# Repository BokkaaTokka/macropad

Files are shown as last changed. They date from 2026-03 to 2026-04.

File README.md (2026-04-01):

# CadPad
**This is my own macropad called CadPad.**

CadPad is designed to provide shortcuts in CAD, but also works for other things by mapping it to anything you want. It is also my very first PCB design.

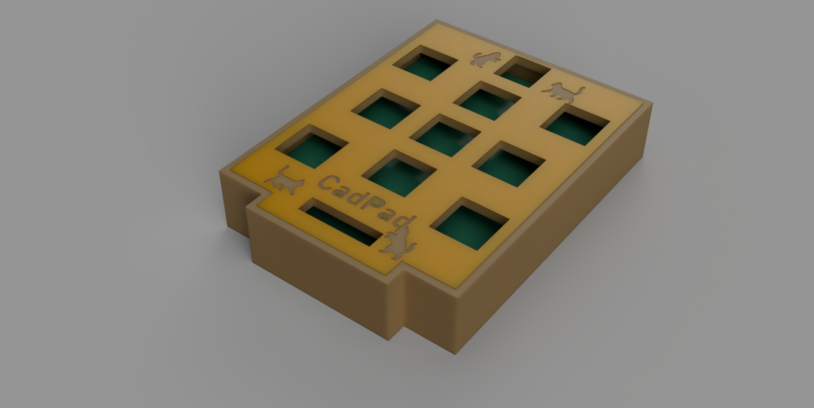
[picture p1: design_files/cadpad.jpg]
My design.


### Problems I faced
I had a really fun time making the PCB, it was my first time, but thanks to the good introduction an the intuitive software, it turned out pretty well.(I think, we'll see when I get the real ones.)
I'm also completely new to QMK-firmware and compiling. I have done a lot of programming before, mainly with micropython/circuitpython/python, but this was something new. I can't tell how happy I was when the console filled up with [OK].

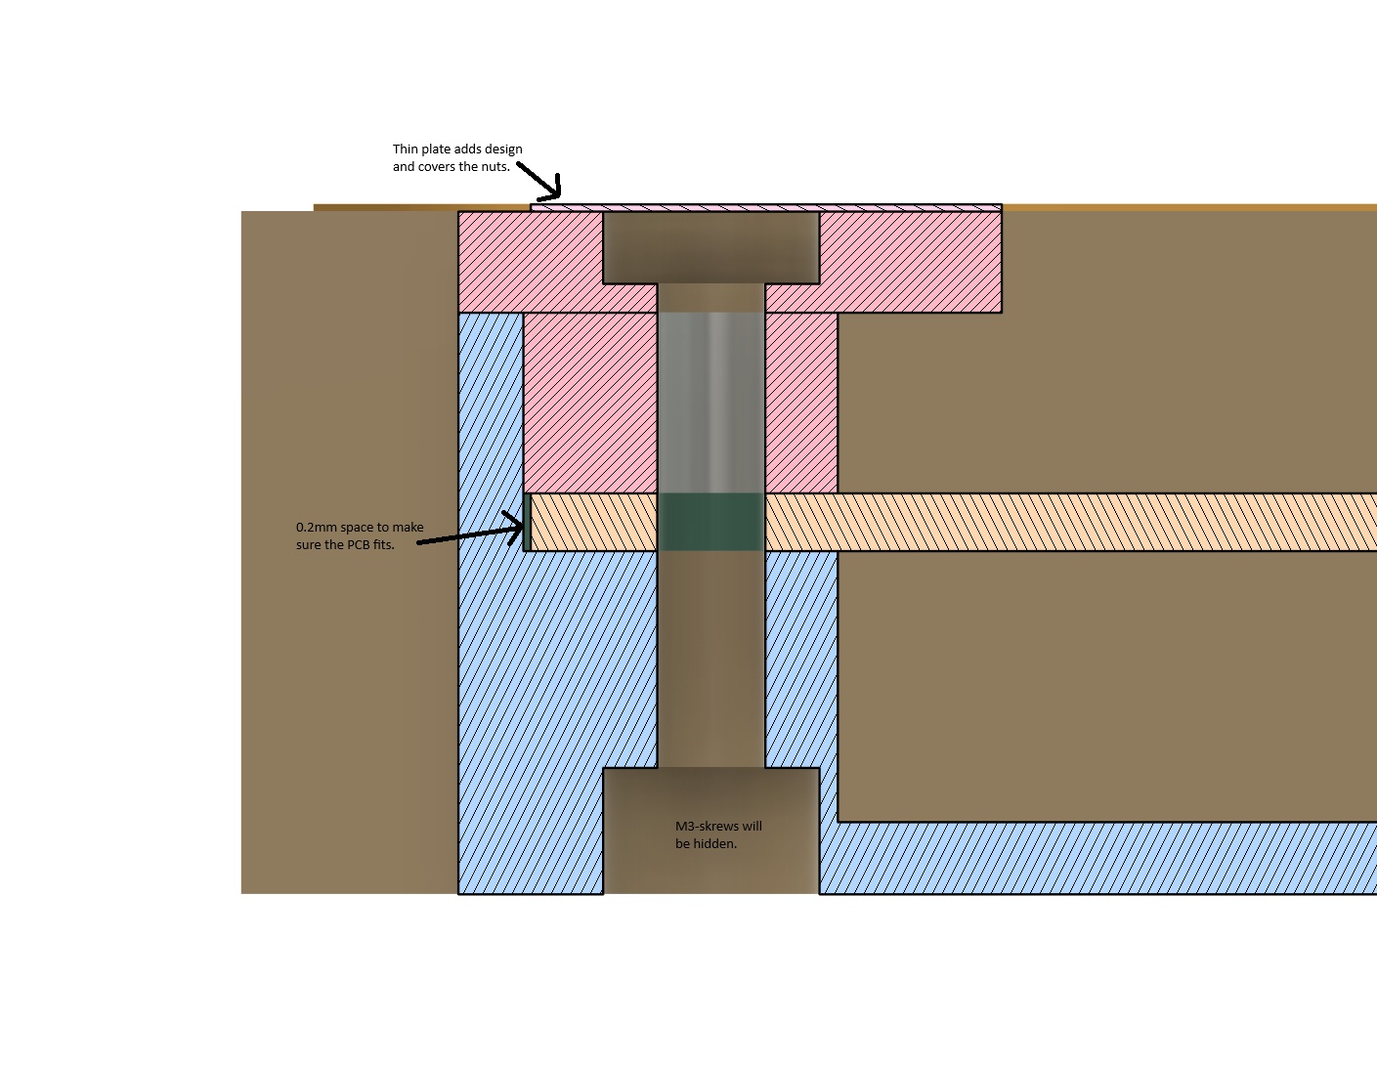
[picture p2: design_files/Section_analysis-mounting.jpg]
Mounting

I wanted to try a kind of mounting that I have never used before. The nut and end of the screw will be covered by a thin plate that also adds some design to the project. This will require me to cut the screws in exact lenghths. The section analysis is slightly outdated, I have for example added some space between the top and base, the vertical ble/pink line.

### BOM
|Unit|Amount|
|:----|:----|
|Cherry MX Switch|9x|
|XIAO rp2040|1x|
|Blank DSA Keycap|9x|
|M3x16 Bolt|4x|
|M3 Nut|4x|
|1N4148 DO-35 Diodes|9x|
|EC11 Rotary Encoder|1x|
|2.54mm straight pin header|18x|
#### I will also use/need
* 3D printed parts
* Custom PCB
* QMK firmware
* Soldering iron

### Current state

I'm done with designing PCB, case and firmware. The current version has two layers, for CAD and normal use, this will be modified later.

Below is a screenshot of the current PCB routing, I had tho change the placing of the diodes, as the may be in the way of the buttons.

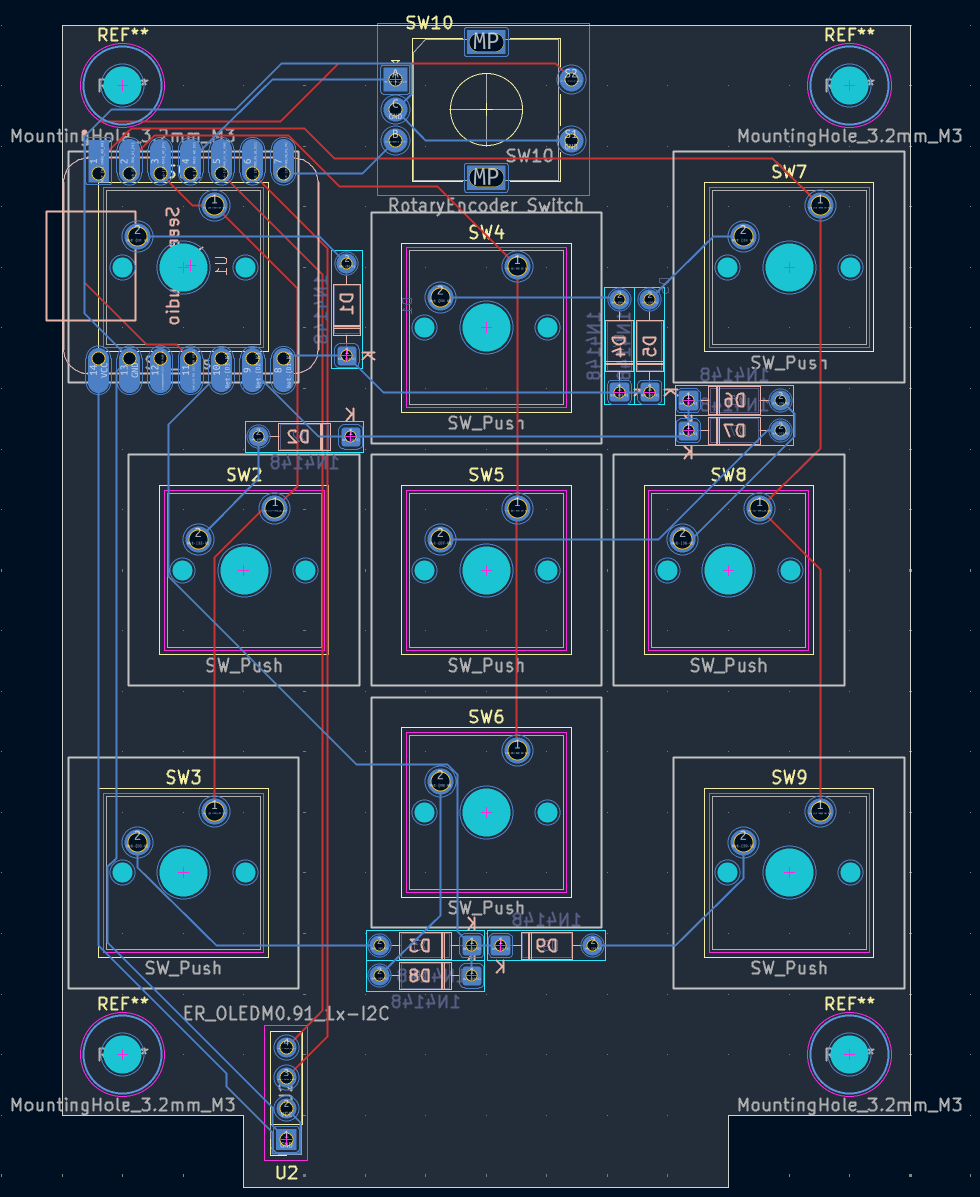
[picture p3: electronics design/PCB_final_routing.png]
Routing


### The future
I will definitly change the firmware a bit once I have tested the functionality, add an animation to the OLED and update the keymap. But it will get a lot easier once I have the physical product to test on.

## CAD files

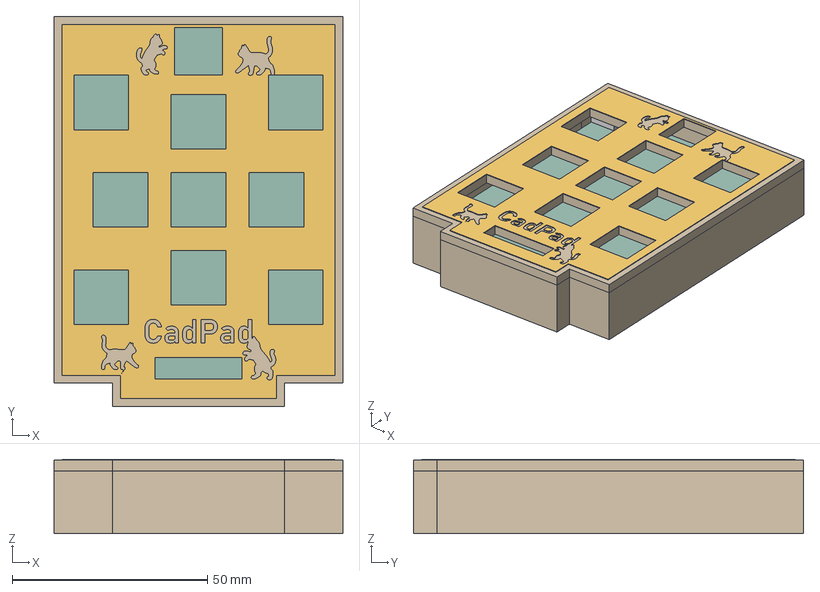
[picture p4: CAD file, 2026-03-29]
design_files/Macropad.step
74.0 x 100.0 x 19.1 mm
case_base
PCB
case_lid
design

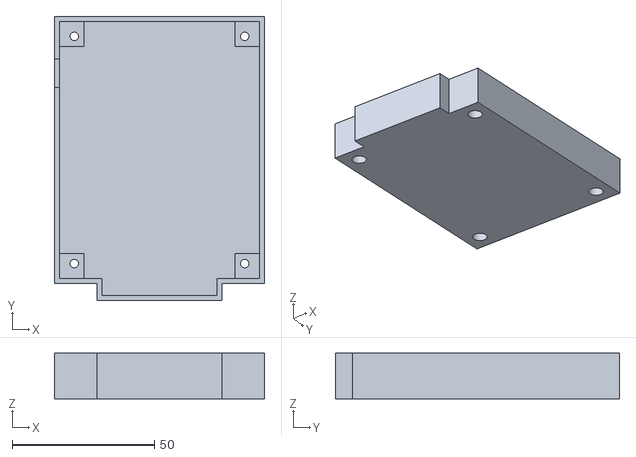
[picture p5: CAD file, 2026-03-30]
production/case_base.stl
74.0 x 100.0 x 16.1

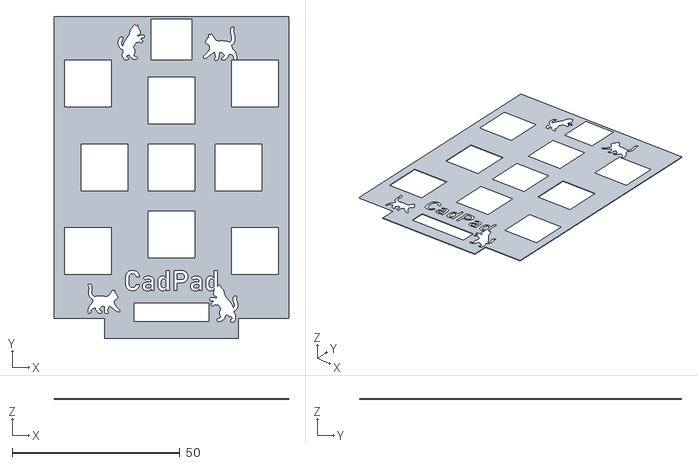
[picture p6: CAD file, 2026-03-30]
production/design.stl
70.0 x 96.0 x 0.2

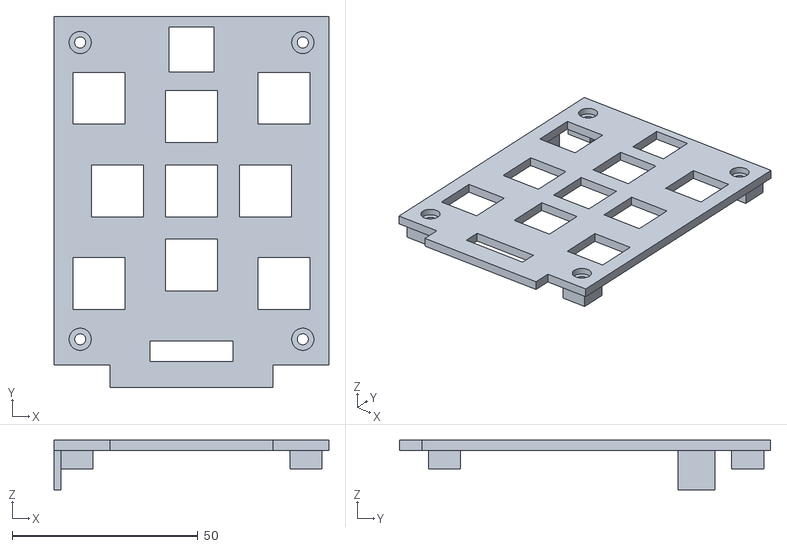
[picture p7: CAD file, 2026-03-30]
production/case_lid.stl
74.0 x 100.0 x 13.4

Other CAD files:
design_files/Macropad.f3d

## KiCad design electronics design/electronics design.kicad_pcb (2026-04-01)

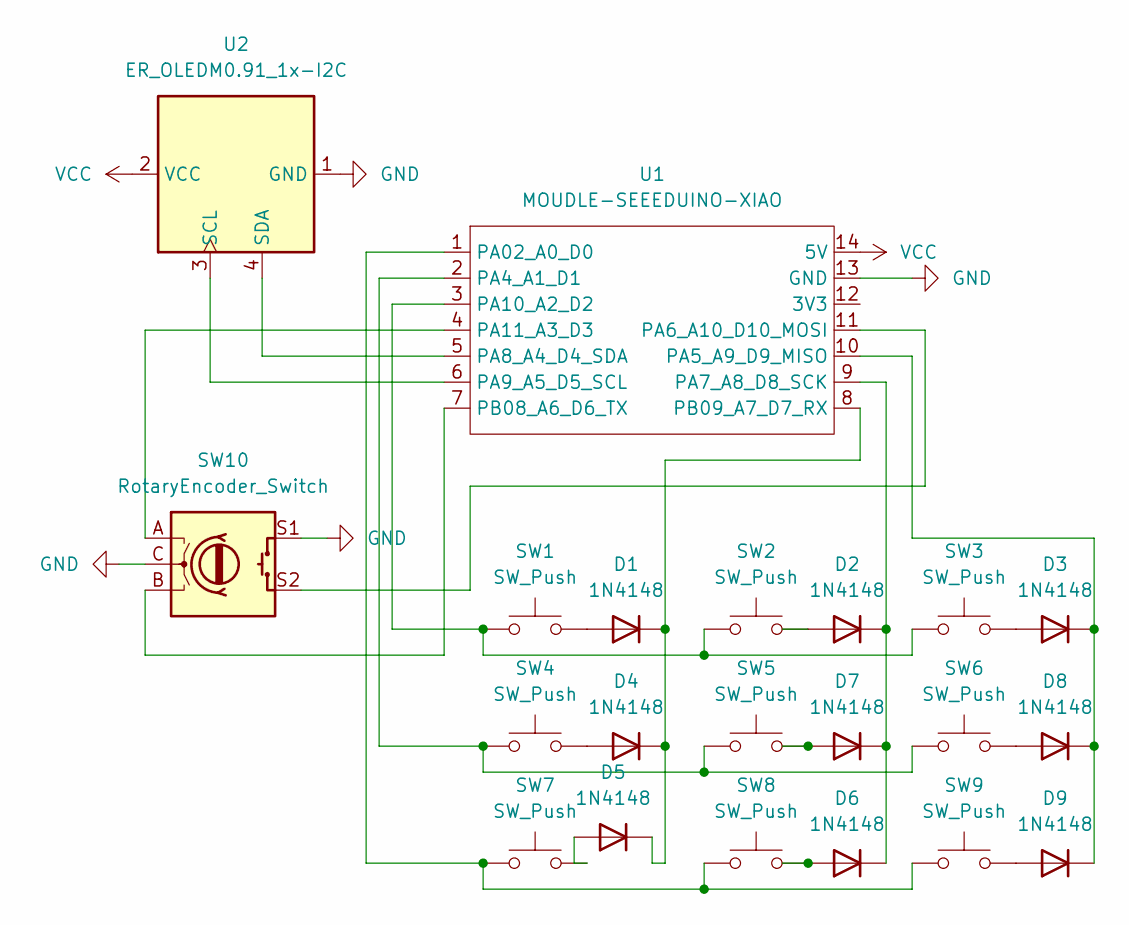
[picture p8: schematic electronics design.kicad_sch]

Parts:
D1, D2, D3, D4, D5, D6, D7, D8, D9: 1N4148; D_DO-35_SOD27_P7.62mm_Horizontal
SW1, SW2, SW3, SW4, SW5, SW6, SW7, SW8, SW9: SW_Push; SW_Cherry_MX_1.00u_PCB_centered
SW10: RotaryEncoder_Switch; RotaryEncoder_Alps_EC11E-Switch_Vertical_H20mm
U1: MOUDLE-SEEEDUINO-XIAO; XIAO-Generic-Hybrid-14P-2.54-21X17.8MM
U2: ER_OLEDM0.91_1x-I2C; PinSocket_1x04_P2.54mm_Vertical

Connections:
GND: SW10.C, SW10.S1, U1.13 (GND), U2.1 (GND)
unnamed: D1.2 (A), SW1.2
unnamed: D1.1 (K), D4.1 (K), D5.1 (K), U1.8 (PB09_A7_D7_RX)
unnamed: D2.2 (A), SW2.2
unnamed: D2.1 (K), D6.1 (K), D7.1 (K), U1.9 (PA7_A8_D8_SCK)
unnamed: D3.2 (A), SW3.2
unnamed: D3.1 (K), D8.1 (K), D9.1 (K), U1.10 (PA5_A9_D9_MISO)
unnamed: D4.2 (A), SW4.2
unnamed: D5.2 (A), SW7.2
unnamed: D6.2 (A), SW8.2
unnamed: D7.2 (A), SW5.2
unnamed: D8.2 (A), SW6.2
unnamed: D9.2 (A), SW9.2
unnamed: SW7.1, SW8.1, SW9.1, U1.1 (PA02_A0_D0)
unnamed: SW4.1, SW5.1, SW6.1, U1.2 (PA4_A1_D1)
unnamed: SW10.S2, U1.11 (PA6_A10_D10_MOSI)
unnamed: U1.5 (PA8_A4_D4_SDA), U2.4 (SDA)
unnamed: U1.6 (PA9_A5_D5_SCL), U2.3 (SCL)
unnamed: SW1.1, SW2.1, SW3.1, U1.3 (PA10_A2_D2)
unnamed: SW10.A, U1.4 (PA11_A3_D3)
unnamed: SW10.B, U1.7 (PB08_A6_D6_TX)
VCC: U1.14 (5V), U2.2 (VCC)

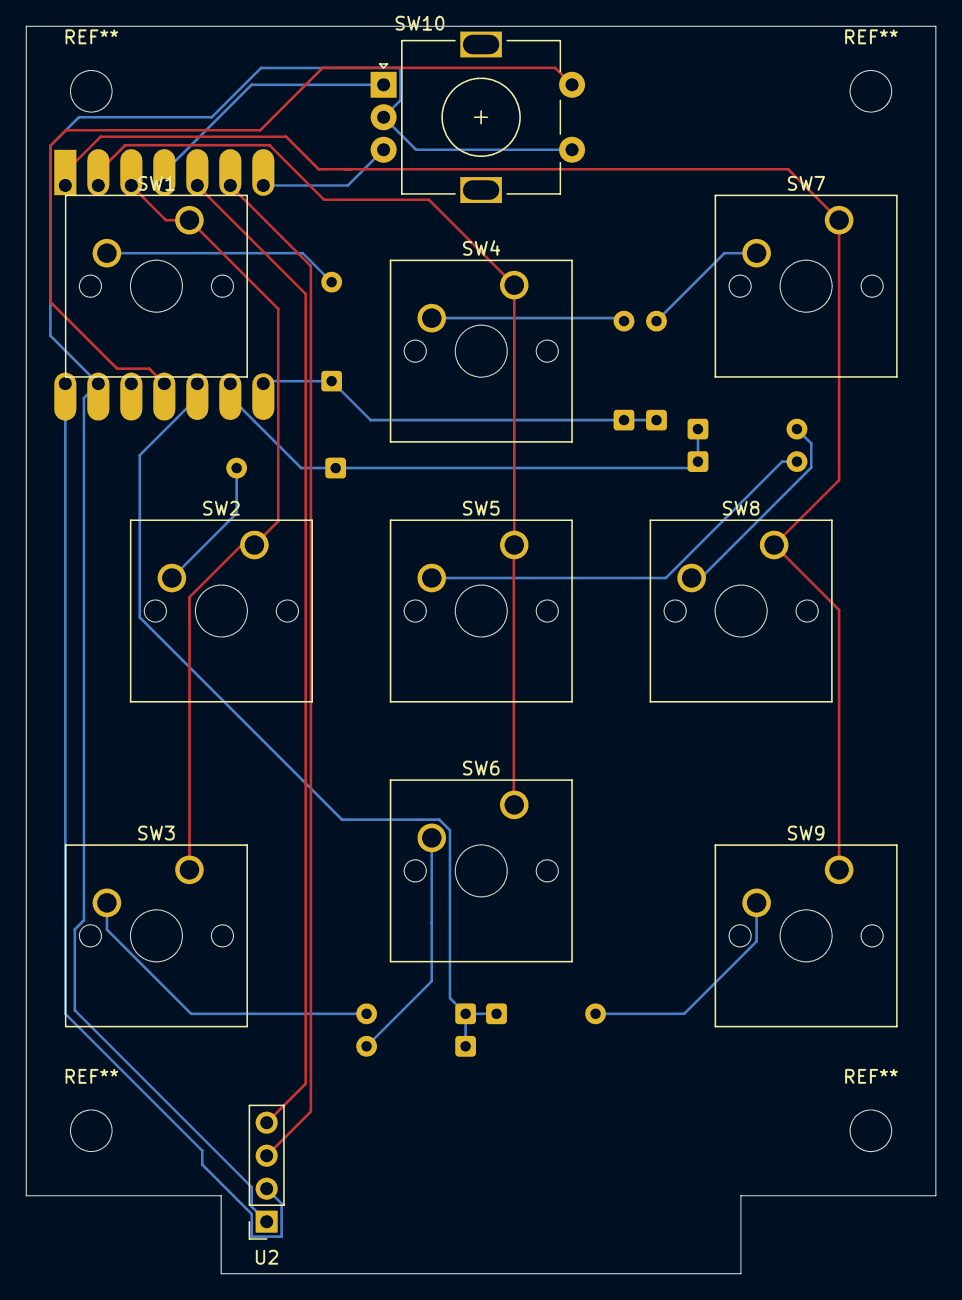
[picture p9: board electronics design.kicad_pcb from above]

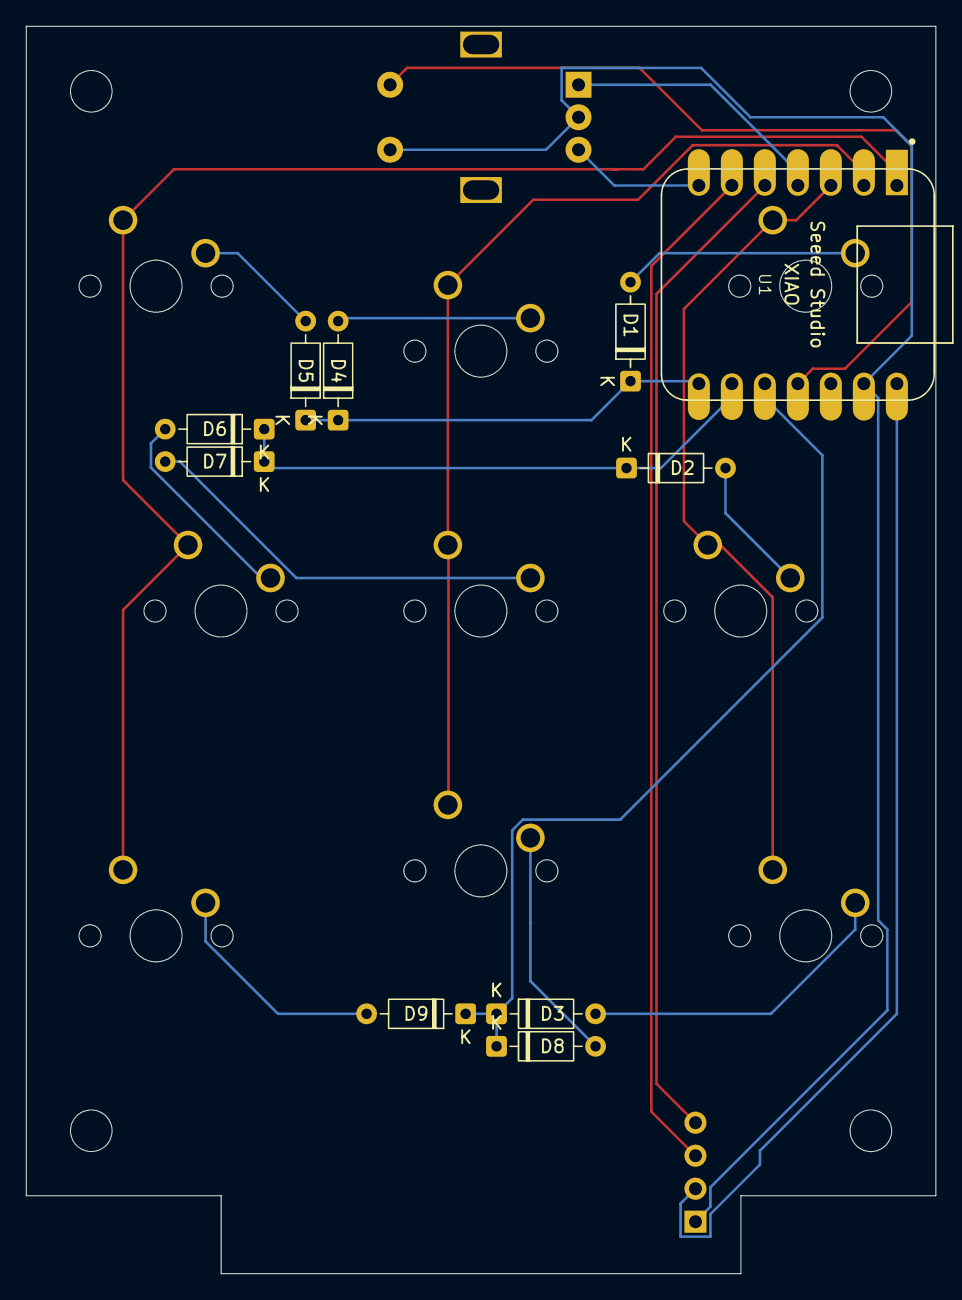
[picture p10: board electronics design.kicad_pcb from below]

Board: 2 copper layers, 70.0 x 96.0 mm, 21 parts (10 on the bottom side), 22 nets.

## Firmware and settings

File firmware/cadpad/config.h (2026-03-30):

#pragma once

#define VENDOR_ID 0x1234
#define PRODUCT_ID 0x5678
#define DEVICE_VER 0x0001

#define I2C_DRIVER I2CD1
#define I2C1_SDA_PIN GP6
#define I2C1_SCL_PIN GP7

#define OLED_DISPLAY_128X32
#define OLED_TIMEOUT 20000

#define ENCODER_A_PINS {GP29}
#define ENCODER_B_PINS {GP0}
#define ENCODER_RESOLUTION 4
#define ENCODER_BTN_PIN GP3

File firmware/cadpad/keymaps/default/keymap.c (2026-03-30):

#include QMK_KEYBOARD_H

enum layers { _BASE, _CAD };

bool encoder_update_user(uint8_t index, bool clockwise) {
    if (clockwise) {
        tap_code(KC_VOLU);
    } else {
        tap_code(KC_VOLD);
    }

    return false;
}



bool encoder_button_state = false;

void matrix_scan_user(void) {
    bool state = gpio_read_pin(ENCODER_BTN_PIN);

    if (state && !encoder_button_state) {
        tap_code(KC_MUTE);
    }

    encoder_button_state = state;
}

#ifdef OLED_ENABLE

bool oled_task_user(void) {
    oled_write_ln("Layer:", false);

    switch (get_highest_layer(layer_state)) {
        case _BASE:
            oled_write_ln("Base", false);
            break;

        case _CAD:
            oled_write_ln("CAD", false);
            break;
    }

    return false;
}

#endif




const uint16_t PROGMEM keymaps[][MATRIX_ROWS][MATRIX_COLS] = {

    [_BASE] = LAYOUT(KC_7, KC_8, TG(_CAD), KC_4, KC_5, KC_6, KC_1, KC_2, KC_3),
    [_CAD]  = LAYOUT(KC_ESC, KC_UP, TG(_CAD), KC_LEFT, KC_ENT, KC_RIGHT, KC_PSCR, KC_DOWN, KC_DEL)

};

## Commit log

2026-03-29 Created the repo.
    [Macropad.f3d, Macropad.step, electronics design.kicad_pcb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]
2026-03-30 Added production and firmware
    [case_base.stl, case_lid.stl, design.stl]
2026-04-01 Changed the position of the diodes to make space for the buttons.
    [electronics design.kicad_pcb]
2026-04-01 Change image caption for PCB routing screenshot
    Updated image reference in README for PCB routing.
